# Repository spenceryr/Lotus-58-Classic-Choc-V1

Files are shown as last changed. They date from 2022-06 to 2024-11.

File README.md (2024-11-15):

### Notice! Project files in the development branches are NOT intended for public use in production of PCB's, may or may not be tested and may change or be removed without notice! 
If you order PCB's from these, YOU bear the sole responsibility for how these turn out!!! Please use the Gerber files for producing PCB's, found under the header 'Releases' instead (Look here >>). Also please note the difference between a 'Pre-release' (partially/fully untested, basically what I order a prototype PCB from to test) and a full actual 'Release' which is fully tested, built and ready to be used to produce PCB's.

# Lotus 58 Glow - Classic
#### Lotus 58 Classic is the wired designs of the Lotus keyboard. Wireless with BLE and 2.4Ghz dongled wireless reside in other repositories.

Starting with simple tweaks to the Lily58 Glow before ordering a set of PCB's it quickly spiraled out of control, and I ended up with what wasn't quite a Lily58 anymore, and although very similar in layout, it is no longer compatible with plate and case design. 

Because of this, it was renamed Lotus58, referencing another flower much like the lily in the name Lily58.

Lotus 58 Glow
(photo from reddit by u/bduzik)

## General Specifications

- Layout very similar to the original Lily58 family
- Per key RGB and RGB underglow
- Kaihl Hot-swap sockets for MX compatible switches
- Can be used as a standalone Gamepad for either hand
- Optional 0.91" OLED Screens and rotary encoders (one each per side)
- All components through-hole and easily soldered for beginners (SMD option for diodes)
- Designed with a sandwich-style plate/case as part of the design

## Layout variations

- Optional plate layout with OLED screen (Encoder can be placed on upper thumb key position)
- Optional plate layout with rotary encoder (Removes OLED screen for that side)  
- Optional plate layout with no hole for OLED or upper encoder (Encoder can be placed on upper thumb key position)

Layout variations Layout Variations

## 3D-printed Cases
**There are a couple of 'official' commissioned designs for 3D printed cases for the Lotus 58 Glow, available in a separate Git [here](https://github.com/TweetyDaBird/Lotus-Cases).** 

And you can find several more made by users using Google, and/or by joining the Discord channel and chatting to the builders/designers and users.

## Things to note when ordering PCB's
### Finding the Gerber files
If you are not aiming at modifying things, don't look for the gerber files in the folders, pretty please!</BR>
And please don't open yet another issue about it! </BR>
The gerber files are where they belong, zipped up in releases, look under that header for the version you want.

### Tips & Tricks
- Most PCB manufacturers have a MOQ of 5 PCB's, meaning you end up with 2½ keyboards when finished.
- The recommended PCB thickness is 1.6 mm, both for the main PCB and plates to allow the keyswitches to grip the plate and lock in place securely.

If ordering from [JLCPCB](https://www.jlcpcb.com) the plate Gerber files include a reference putting the added serial etc on a breakaway part for a clean look with minimal cost, if using another manufacturer it's possible they have additional fee's for removing the extra text, or you should consider plotting the Gerber files yourself with the correct reference for your manufacturer. Otherwise use the standard settings from JLPCB.

## Build guide
**Some basic build instructions are in the [WIKI](https://github.com/TweetyDaBird/Lotus-58-Classic/wiki), and I really try to keep these updated.** But please keep in mind that whenever these instructions conflict with information on the PCB silkscreen, the silkscreen is and always will be the correct source of information! It's always updated with the version, and the most current information for the PCB version in question. 

**The intent has always been that the keyboard should be able to be fully built with some very basic soldering skills and the instructions on the silkscreen.**

### Discord for further build help and discussions!

<a href="https://discord.gg/G6QzcJQUnm">Discuss on Discord</a>

## Buy a kit!
I sell complete kits, making it easy to build your keyboard, and it also supports prototypes for new wacky ones. 



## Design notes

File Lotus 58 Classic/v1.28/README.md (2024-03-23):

# Lotus 58 v1.28

Starting with simple tweaks to the Lily58 Glow before ordering a set of PCB's it quickly spiraled out of control, and I ended up with what wasn't quite a Lily58 anymore, and although very similar in layout, it is no longer compatible with plate and case design. 

Because of this, it was renamed Lotus58, referencing another flower much like the lily in the name Lily58.

# Lotus 58 Glow

Lotus 58 Glow
(photo from reddit by u/bduzik)

Fully backwards compatible physically identical outline for plates and identical firmware. Updates required to 3D cases for the reset/power switch.

# Parts needed

| Name of part | Qty. | Optional | Remarks | Aliexpress |
| --- | ---- | --- | --- | --- |
| PCB | 2 | X | 1,6 mm thick | X |
| Top plate | 2 | X | Optional layouts for OLED or encoder in top position. | X |
| Bottom plate | 2 | X | X | X |
| Kailh hotswap socket | 56-58 | X | Qty. depends on layout. | [link](https://www.aliexpress.com/item/-/4001051840976.html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) |
| Diodes 1N4841 (TH) or 1N4148W (SMD) | 56-58 | X | Qty. depends on layout. TH recommended for beginners. | [link(TH)](https://www.aliexpress.com/item/HOT-SELL-100-PCS-1N4148-DO-35-IN4148-Silicon-Switching-Diode-FREE-SHIPPMENT/32660088529.html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) or [link(SMD)](https://www.aliexpress.ru/item/-/1005002059571417.html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) |
| Capacitors 100 nF | 0-4 | ✔ | Qty. depends on layout. 2 needed for each encoder installed. | [link](https://www.aliexpress.com/item/-/32971478818.html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) |
| Resistor 4.7 kOhm | 0-4 | ✔ | Qty. depends on layout. 2 needed for each OLED installed. | [link](https://www.aliexpress.com/item/-/32847047012.html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) |
| 0.91" OLED Display | 0-2 | ✔ | Qty. depends on layout. | [link](https://www.aliexpress.com/item/-/4001028384269.html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) |
| TRRS jack PJ-320A | 2 | X | X | [link](https://www.aliexpress.com/item/-/4000114275750.html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) |
| M2 * 12 mm standoff | 10 | X | Rounded, max 3.7 mm in diameter | [link](https://www.aliexpress.com/item/-/32863484622.html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) |
| M2 * 4 mm screw | 20 | X | 4-8 mm length fits, low profile hex head recommended | [link](https://www.aliexpress.com/item/-/32966917947.html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) |
| TRRS cable | 1 | X | Needs to be 4 poles, more common 3 poles cable creates a shortcircuit | [link](https://www.aliexpress.com/item/32905903526.html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,searchweb201602_,searchweb201603_) |
| Silicon pads | 10 | X | X | [link](https://www.aliexpress.com/item/-/32912066603.html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) |
| Pro Micro | 2 | X | Can be built with various ProMicro clones as well as Elite C (Or nice!nano for a wireless keyboard) | [link](https://www.aliexpress.com/item/-/32849563958.html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) |
| MillMax low profile sockets | 1 | ✔ | Purchased as 1x64 pin and split | [link](https://eu.mouser.com/ProductDetail/575-641503)|
| Rotary Encoder | 0-2 | ✔ | Qty. depends on layout. | [link](https://www.aliexpress.com/item/10000056483250.html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,searchweb201602_,searchweb201603_) |
| Rotary Encoder Knob | 0-2 | ✔ | One needed for each encoder. Clearance for max 24 mm diameter, pick halfshaft or spline according to encoder choice.  | [link](https://www.aliexpress.com/item/10000056483250.html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,searchweb201602_,searchweb201603_) |
| SK6803/SK6805/SK6812 mini-E (3228) | 12/58 (70) | ✔ | Qty. depends on layout and if used as per-key or underglow (or both). Mini E are winged for easier soldering. | [link](https://www.aliexpress.com/item/4000475685852.html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,searchweb201602_,searchweb201603_) |
| SRV05-4	ESD | 0-2 | ✔ | Optional but recommended for ESD protection. | [link](https://www.lcsc.com/product-detail/Electrostatic-and-Surge-Protection-TVS-ESD_TECH-PUBLIC-SRV05-4_C558418.html)|
| MSK12C02 Slide switch | 0-2 | ✔ | Optional RGB select or Power switch | [link](https://www.lcsc.com/product-detail/Slide-Switches_SHOU-HAN-MSK12C02_C431540.html)|

## Things to note when ordering PCB's
### Finding the Gerber files
If you are not aiming at modifying things, don't look for the gerber files in the folders, pretty please!</BR>
And please don't open yet another issue about it! </BR>
The gerber files are where they belong, zipped up in releases, look under that header for the version you want.

### Tips & Tricks
- Most PCB manufacturers have a MOQ of 5 PCB's, meaning you end up with 2½ keyboards when finished.
- The recommended PCB thickness is 1.6 mm, both for the main PCB and plates to allow the keyswitches to grip the plate and lock in place securely.

If ordering from [JLPCB](https://www.jlpcb.com) the plate Gerber files include a reference putting the added serial etc on a breakaway part for a clean look with minimal cost, if using another manufacturer it's possible they have additional fee's for removing the extra text, or you should consider plotting the Gerber files yourself with the correct reference for your manufacturer. Otherwise use the standard settings from JLPCB.

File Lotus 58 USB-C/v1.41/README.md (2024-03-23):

# Lotus 58 v1.41

Starting with simple tweaks to the Lily58 Glow before ordering a set of PCB's it quickly spiraled out of control, and I ended up with what wasn't quite a Lily58 anymore, and although very similar in layout, it is no longer compatible with plate and case design. 

Because of this, it was renamed Lotus58, referencing another flower much like the lily in the name Lily58.

# Lotus 58 Glow

Lotus 58 Glow
(photo from reddit by u/bduzik)

Fully compatabile with v1.11, physically identical outline for plates etc. and identical Firmware.

# Parts needed

| Name of part | Qty. | Optional | Remarks | Aliexpress |
| --- | ---- | --- | --- | --- |
| PCB | 2 | X | 1,6mm thick | X |
| Top plate | 2 | X | Optional layouts for OLED or encoder in top position. | X |
| Bottom plate | 2 | X | X | X |
| Kailh hotswap socket | 56-58 | X | Qty. depends on layout. | [link](https://www.aliexpress.com/item/-/4001051840976.html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) |
| Diodes 1N4841 (TH) or 1N4148W (SMD) | 56-58 | X | Qty. depends on layout. TH recommended for beginners. | [link(TH)](https://www.aliexpress.com/item/HOT-SELL-100-PCS-1N4148-DO-35-IN4148-Silicon-Switching-Diode-FREE-SHIPPMENT/32660088529.html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) or [link(SMD)](https://www.aliexpress.ru/item/-/1005002059571417.html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) |
| Capacitors 100 nF | 0-4 | ✔ | Qty. depends on layout. 2 needed for each encoder installed. | [link](https://www.aliexpress.com/item/-/32971478818.html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) |
| 0.91" OLED Display | 0-2 | ✔ | Qty. depends on layout. | [link](https://www.aliexpress.com/item/-/4001028384269.html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) |
| USB C Connector | 2 | X | X | [link](https://www.lcsc.com/product-detail/USB-Connectors_G-Switch-GT-USB-7014C_C963373.html) |
| SRV05-4	ESD | 2 | X | ESD protection for USB link. | [link](https://www.lcsc.com/product-detail/Electrostatic-and-Surge-Protection-TVS-ESD_TECH-PUBLIC-SRV05-4_C558418.html)|
| Ferrite bead | 4 | X | ESD protection for USB link. | [link](https://www.lcsc.com/product-detail/Ferrite-Beads_Murata-Electronics-BLM18SG700TZ1D_C882974.html) |
| M2 * 10 mm standoff | 10 | X | Rounded, max 3.7 mm in diameter | [link](https://www.aliexpress.com/item/-/32863484622.html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) |
| M2 * 4 mm screw | 20 | X | 4-8 mm length fits, low profile hex head recommended | [link](https://www.aliexpress.com/item/-/32966917947.html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) |
| Silicon pads | 10 | X | X | [link](https://www.aliexpress.com/item/-/32912066603.html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) |
| Pro Micro | 2 | X | Can be built with various ProMicro clones as well as Elite C (Or nice!nano for a wireless keyboard) | [link](https://www.aliexpress.com/item/-/32849563958.html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) |
| MillMax low profile sockets | 1 | ✔ | Purchased as 1x64 pin and split | [link](https://eu.mouser.com/ProductDetail/575-641503)|
| Rotary Encoder | 0-2 | ✔ | Qty. depends on layout. | [link](https://www.aliexpress.com/item/10000056483250.html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,searchweb201602_,searchweb201603_) |
| Rotary Encoder Knob | 0-2 | ✔ | One needed for each encoder. Clearance for max 24 mm diameter, pick halfshaft or spline according to encoder choice.  | [link](https://www.aliexpress.com/item/10000056483250.html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,searchweb201602_,searchweb201603_) |
| SK6803/SK6805/SK6812 mini-E (3228) | 12/58 (70) | ✔ | Qty. depends on layout and if used as per-key or underglow (or both). Mini E are winged for easier soldering. (Note, these are often sold marked as 3535.)| [link](https://www.aliexpress.com/item/4000475685852.html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,searchweb201602_,searchweb201603_) |
| MSK12C02 Slide switch | 0-2 | ✔ | Optional RGB select or Power switch | [link](https://www.lcsc.com/product-detail/Slide-Switches_SHOU-HAN-MSK12C02_C431540.html)|

## Things to note when ordering PCB's
### Finding the Gerber files
If you are not aiming at modifying things, don't look for the gerber files in the folders, pretty please!</BR>
And please don't open yet another issue about it! </BR>
The gerber files are where they belong, zipped up in releases, look under that header for the version you want.

### Tips & Tricks
- Most PCB manufacturers have a MOQ of 5 PCB's, meaning you end up with 2½ keyboards when finished.
- The recommended PCB thickness is 1.6 mm, both for the main PCB and plates to allow the keyswitches to grip the plate and lock in place securely.

If ordering from [JLPCB](https://www.jlpcb.com) the plate Gerber files include a reference putting the added serial etc on a breakaway part for a clean look with minimal cost, if using another manufacturer it's possible they have additional fee's for removing the extra text, or you should consider plotting the Gerber files yourself with the correct reference for your manufacturer. Otherwise use the standard settings from JLPCB.

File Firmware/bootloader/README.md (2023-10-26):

# How do I flash nanoBoot to my Pro Micro controllers?

**Please note that this does NOT apply to RP2040 based controllers at all!**

## Flash the bootloader with an external programmer
Download the `nanoBoot-bootloader.hex` file and flash it using your choice of software/hardware.

#### Required fuse settings:
- lfuse memory = 0xFF or 0x7F (CKDIV8=1 or 0, 16CK+65ms)
- hfuse memory = 0xD6 (EESAVE=0, BOOTRST=0)
- efuse memory = 0xC7 (=0xF7, No BOD)

#### Example of fuse command
-U lfuse:w:0x7F:m -U hfuse:w:0xD6:m -U efuse:w:0xC7:m

## Using a pair of Pro Micro controllers as ISP programmers to flash the bootloader to both.
**This requires no external hardware, besides a few wires, and a little patience and time.** This way, you can easily and cheaply use the classic Atmega32u4 Pro Micro controllers a while longer, with either a full featured QMK keymap, or Vial if you accept some limitations in what features will fit.

1. Install Arduino IDE 1.8.19 and Pro Micro support:
  - Go to Files -> Preferences;
  - Paste `https://raw.githubusercontent.com/sparkfun/Arduino_Boards/master/IDE_Board_Manager/package_sparkfun_index.json` into "Additional Boards Manager URLs", press OK;
  - Go to Tools -> Board -> Boards Manager;
  - Search for `SparkFun AVR Boards`, install that, close the dialog window.
2. Burn the ArduinoISP sketch (through the normal USB connection):
  - Connect one of your two Pro Micros (we will call it `A` from now on);
  - In Arduino IDE, go to Tools -> Board -> SparkFun AVR Boards -> SparkFun Pro Micro;
  - As Processor choose the 5V 16MHz version;
  - As Port choose whatever the Arduino IDE gives you as an option (If you have more than 1 serial device connected, figure out which port is your Pro Micro by plugging and unplugging it)
  - In Arduino IDE, go to File -> Examples -> ArduinoISP -> ArduinoISP;
  - Hit Upload (either the arrow to the right next to the checkmark, or in Sketch -> Upload);
  - Close the Arduino IDE.
3. Connect the two Pro Micros:
  - Disconnect the Pro Micro `A` from the computer, get 6 jumper wires;
  - Connect the GND pin to GND pin, VCC to VCC, 15 to 15, 14 to 14, 16 to 16;
  - PAY ATTENTION: Connect the pin 10 of the Pro Micro `A`, to RST of the Pro Micro `B`;
  - Plug the Pro Micro `A` back into the computer.
4. Burn the supplied `nanoBoot-bootloader.hex` to the Pro Micro `B` (using `A´ as the ISP):
  - Now we will use `avrdude` included in the Arduino as a standalone executable (These instructions assume you use a terminal for your OS);
  - In the terminal go to the location where you downloaded the supplied `nanoBoot_ArduinoISP.hex` (use the `cd` command to jump between directories, `ls` (MacOS/Linux) or `dir` (Windows) displays content)
  - Run this command: `avrdude -c stk500v1 -p atmega32u4 -P /dev/ttyACM0 -b 19200 -U flash:w:nanoBoot-ArduinoISP.hex:i -U lfuse:w:0x7F:m -U hfuse:w:0xD6:m -U efuse:w:0xC7:m`  **WARNING: This command sets fuses on the board and wrong values of the fuses can brick the board beyond repair. This is done at your own responsibility!!** *Note: you might need to change the serial port given after -P from what is shown here, it should be the same you used when uploading the sketch through Arduino IDE.*
  - This flashes the same ArduinoISP sketch, but with the nanoBoot bootloader already included.
5. Burn the nanoBoot bootloader to the Pro Micro `A`:
  - Disconnect the Pro Micro `A` from the computer;
  - Swap the connections between the Pro Micros, since you will now swap the roles of the Pro Micros - Connect Pro Micro `A`'s RST to Pro Micro `B`'s pin 10;
  - Connect the Pro Micro `B` to the computer;
  - Run the same command as in step 4 (**the same warning applies**);
  - Congratulations! Now you have two Pro Micros with nanoBoot bootloaders!
6. Flash the Lotus58 firmware either from QMK Configurator, or using an already compiled binary
7. Test and celebrate!

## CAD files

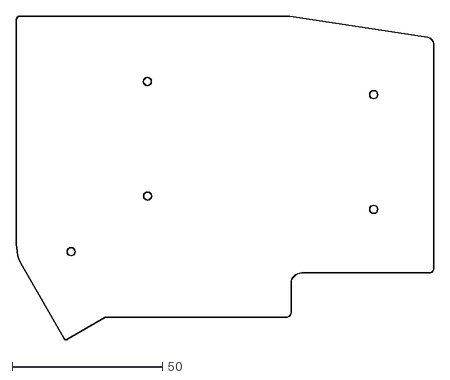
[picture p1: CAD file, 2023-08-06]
Plate/DXF/Laser_Cut_Bottom_Plate.dxf
139.1 x 107.7

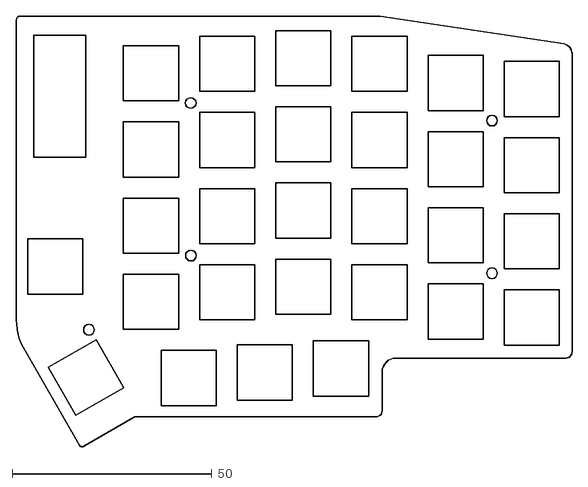
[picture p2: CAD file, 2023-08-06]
Plate/DXF/Laser_Cut_Top_Plate_OLED.dxf
139.1 x 107.7

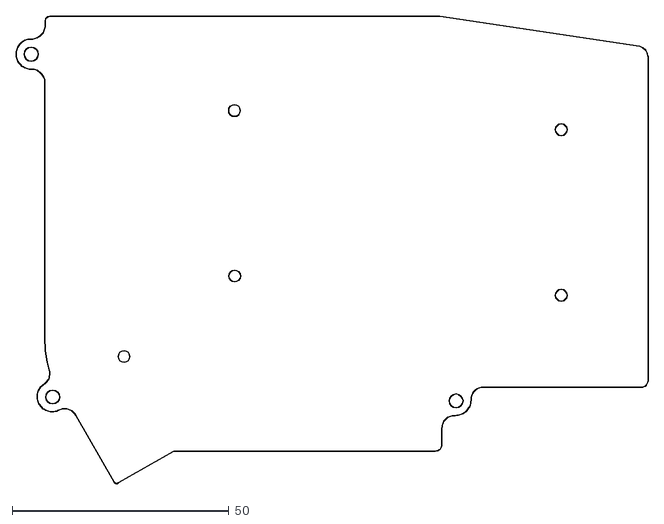
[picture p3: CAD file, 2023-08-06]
Plate/DXF/Laser_Cut_Bottom_Plate_TENT.dxf
145.7 x 107.7

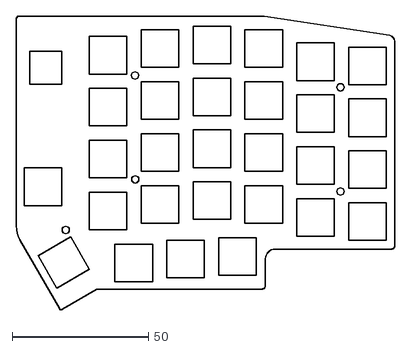
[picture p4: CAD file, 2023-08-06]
Plate/DXF/Laser_Cut_Top_Plate_ENC.dxf
139.1 x 107.7

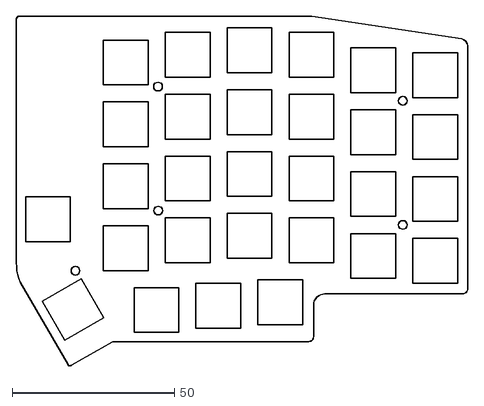
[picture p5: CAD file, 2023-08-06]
Plate/DXF/Laser_Cut_Top_Plate_Blank.dxf
139.1 x 107.7

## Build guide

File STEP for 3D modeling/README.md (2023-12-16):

### STEP files used for 3D modeling cases etc.
All relevant components are modeled and present on both sides of the PCB, as they are not always 100% symmetrical (placement depends on traces etc). Keep in mind that the modeling should as standard use the component placed on the bottom side of the PCB for each respective hand.

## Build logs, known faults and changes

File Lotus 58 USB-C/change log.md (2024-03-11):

Change Log Lotus 58 Glow USB-C

- v1.30 - Initial release
   - This version adds an USB-C link between hands instead of the TRRS link. This allows hot-plugging the link without damage.
   - NO support for wirless builds (battery/power switch) as the USB-C link isn't suitable for this.
- v1.33 - Intermediary release
  - Minor tweaks to the ESD protection circuit
  - The RGB circuit now allows ALL RGB to be soldered in place, and switches the powerline instead of the data line as previously.
  - ALL RGB uses SK6812 mini-e
  - Reset switch and slide switch is moved for better 3D printed cases. 
- v1.40 - Second major release
  - Moved serial data to D+/- for better cable compatibility.
  - Added solder jumpers for RGB selection without switch
- v1.41 - Intermediary release
  - Corrected minor silkscreen inconsistencies.

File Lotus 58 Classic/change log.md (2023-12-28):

Change Log Lotus 58 Glow TRRS/Classic

- v1.00 - Initial release
   - This verison unfortunately had various RGB issues. Used through hole mounted SK6812 mini RGB's for both per-key and glow.
- v1.11 - Intermediary release
  - RGB issues fixed, improved silkscreen for easier building.
- v1.23 - Second release
  - Greatly improved design, per-key moved to SK6812 mini-e winged RGB, and glow remains as surface mounted SK6812 mini.
  - Added support for battery connector and power switch for wireless builds.
- v1.24 - Intermediary release
   - Added Silkscreen build instructions
  - Added TRRS ESD protection
  - Removed i2c resistors
  - Repositioned reset for easier access
  - Minor cleanup of routing and silkscreen
- v1.26 - Third Release
  - Brings TRRS variant to feature parity with USB C variant by moving ALL RGB to SK6812 mini-e.
  - All RGB can be soldered, and either glow or key can be selected to be active (drawing power)
  - Switch positions are the same as USB-C so reset and power switch can now be on both sides of PCB (easier 3D printing)
  - Better footprints, so easier to solder.
  - Since the TRRS version already have a power switch, the RGB is an internal switch, placed where you need to disassemble, alternatively hard soldered jumpers.
- v1.27 - Intermediary release
  - Improved Silkscreen/build instructions on PCB
- v1.28 - Fourth release
  - Possible to select the function of the external slide switch, setting it as a power switch for wireless builds, or to select RGB for a wired build

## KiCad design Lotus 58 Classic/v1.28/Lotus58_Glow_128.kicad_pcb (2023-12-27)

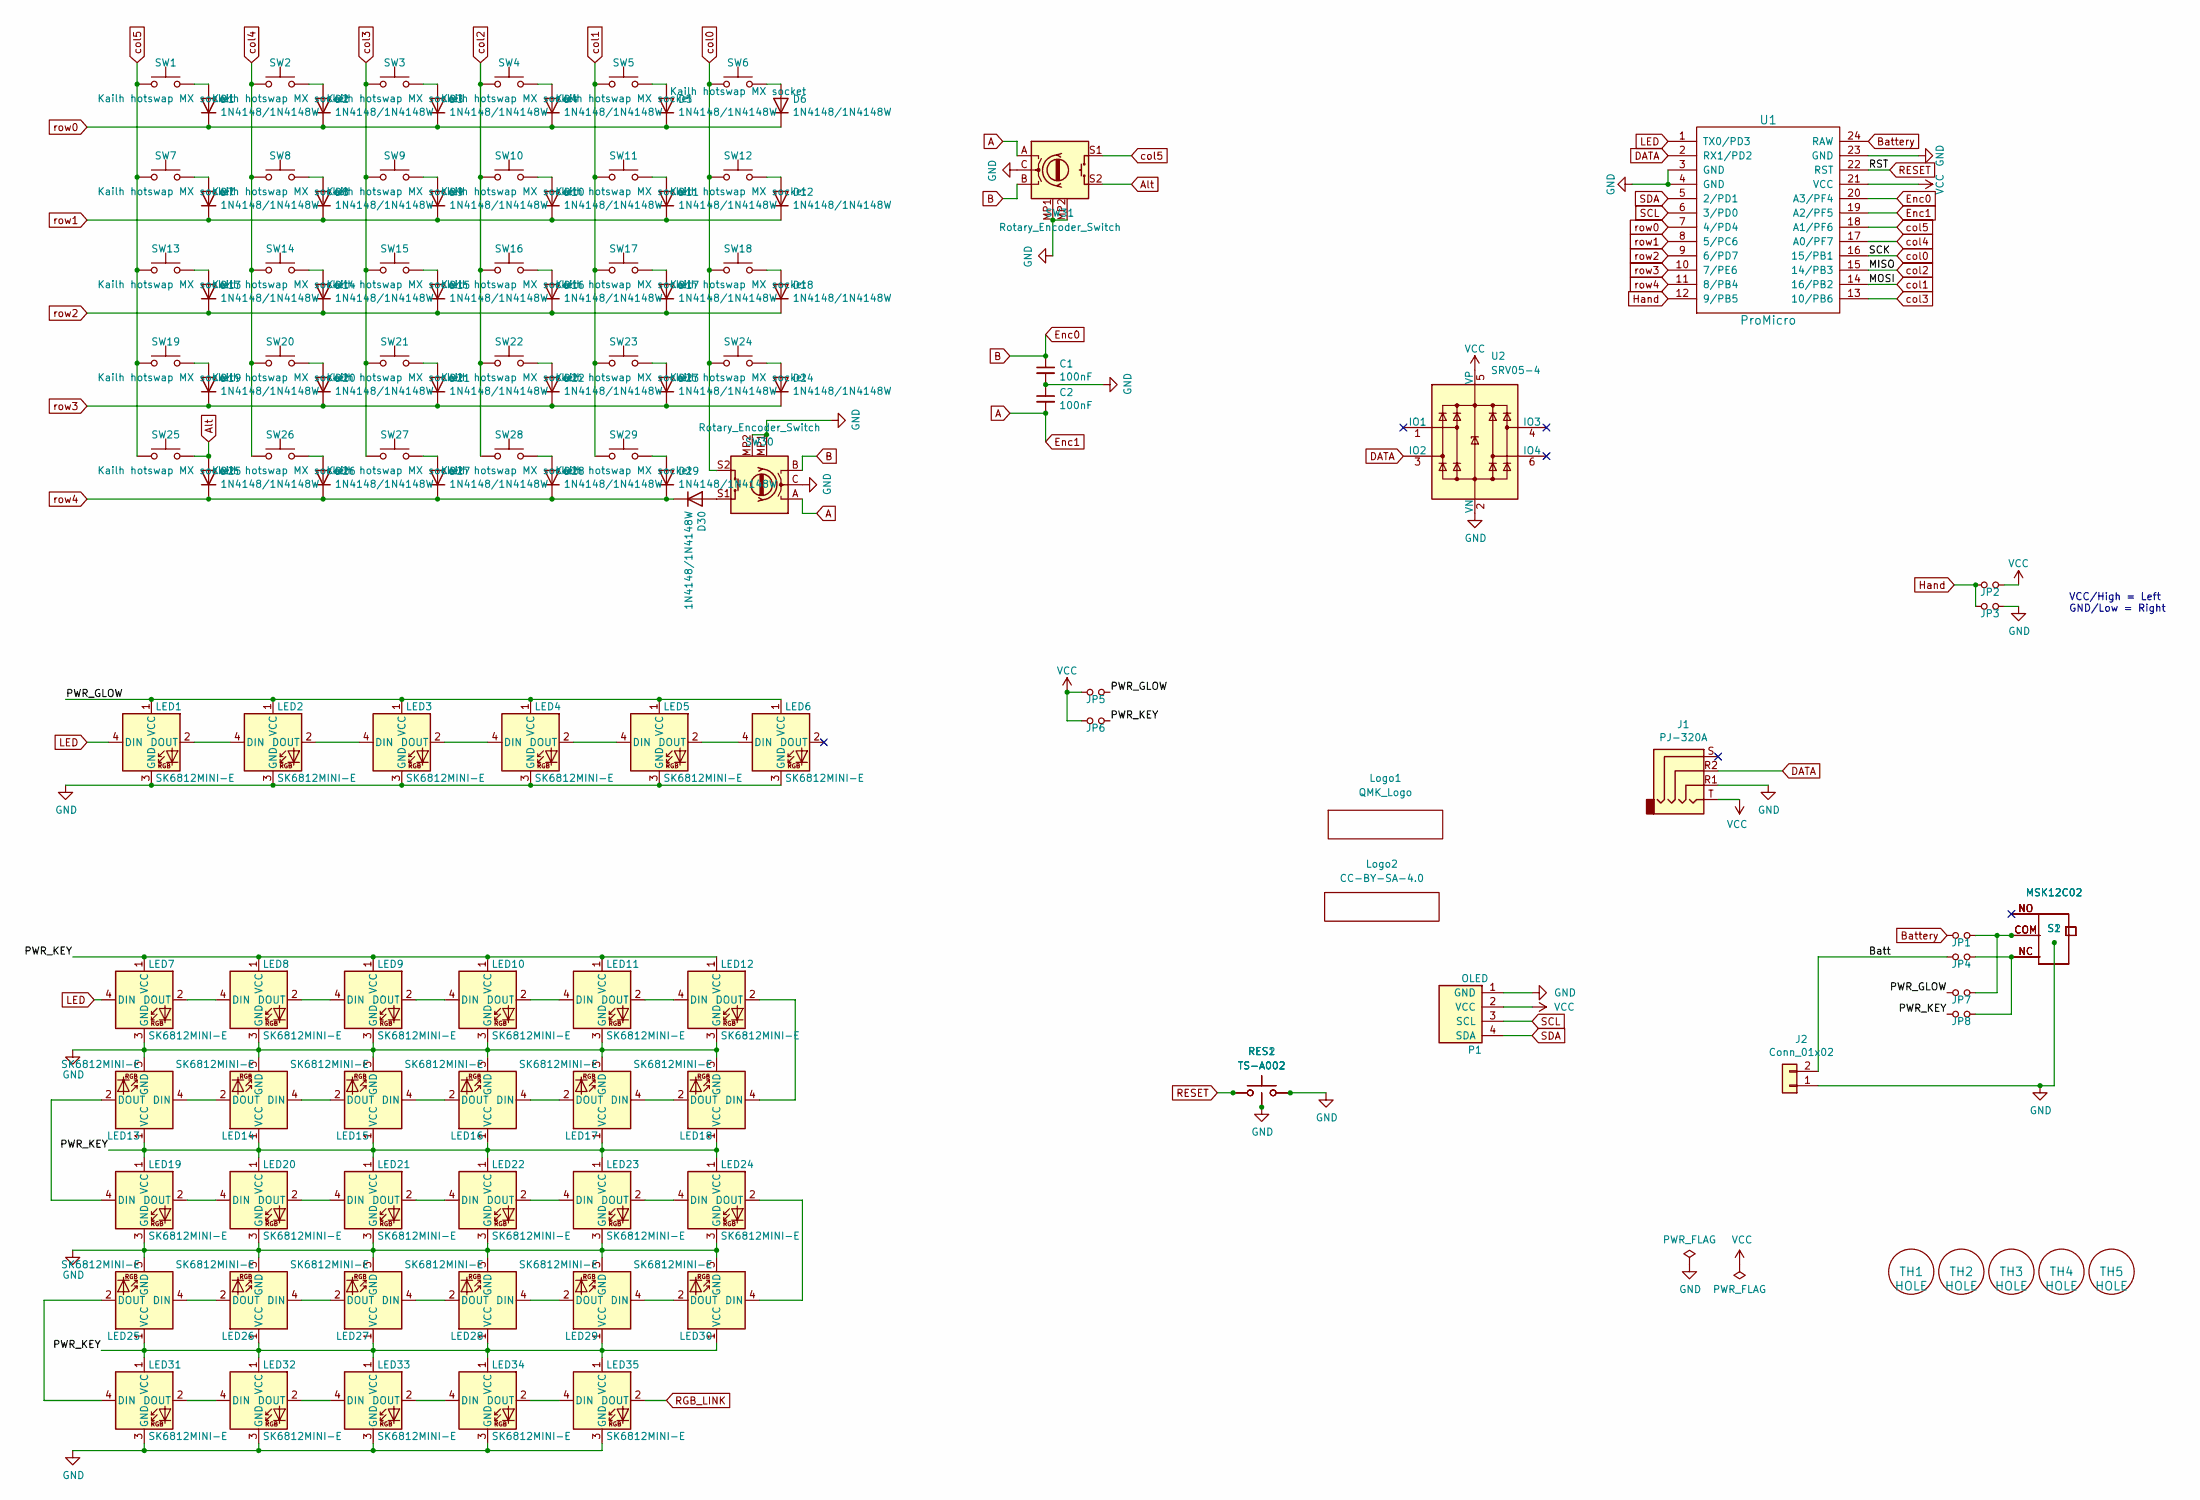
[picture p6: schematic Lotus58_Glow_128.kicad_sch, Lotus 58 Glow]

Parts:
C1, C2: 100nF; RESISTOR_Reversible
D1, D2, D3, D4, D5, D6, D7, D8, D9, D10, D11, D12, D13, D14, D15, D16, D17, D18, D19, D20, D21, D22, D23, D24, D25, D26, D27, D28, D29, D30: 1N4148/1N4148W; Diode_DO35_SOD123
J1: PJ-320A; MJ-4PP-9_alim
J2: Conn_01x02; PinHeader_1x02_P2.54mm_Vertical
JP1, JP4, JP5, JP6, JP7, JP8: FULL; Jumper_min_v2
JP2: LEFT; Jumper_min_v2
JP3: RIGHT; Jumper_min_v2
LED1, LED2, LED3, LED4, LED5, LED6, LED7, LED8, LED9, LED10, LED11, LED12, LED13, LED14, LED15, LED16, LED17, LED18, LED19, LED20, LED21, LED22, LED23, LED24, LED25, LED26, LED27, LED28, LED29, LED30, LED31, LED32, LED33, LED34, LED35: SK6812MINI-E; MX_SK6812MINI-E_REVERSIBLE
Logo1: QMK_Logo; qmk logo
Logo2: CC-BY-SA-4.0; CC_BY_SA_40_line
P1: OLED; SSD1306-0.91-OLED-4pin-128x32 doublesided
RES1, RES2: TS-A002; YTS-A002; LCSC C2888934
S1, S2: MSK12C02; Manufacturer_Part_Number MSK12C02
SW1, SW2, SW3, SW4, SW5, SW6, SW7, SW8, SW9, SW10, SW11, SW12, SW13, SW14, SW15, SW16, SW17, SW18, SW19, SW20, SW21, SW22, SW23, SW24, SW25, SW26, SW27, SW28, SW29: Kailh hotswap MX socket; Kailh_socket_MX_reversible_RGB
SW30: Rotary_Encoder_Switch; RotaryEncoder_Alps_EC11E-Switch_Vertical_H20_special
SW31: Rotary_Encoder_Switch; RotaryEncoder_Alps_EC11E-Switch_Special
TH1, TH2, TH3, TH4, TH5: HOLE; Spacer PCB hole
U1: ProMicro; ProMicro_Reversible_orig
U2: SRV05-4; SOT-23-6

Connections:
/Batt: J2.2, JP4.1
/PWR_GLOW: JP5.2, JP7.1, LED1.1 (VCC), LED2.1 (VCC), LED3.1 (VCC), LED4.1 (VCC), LED5.1 (VCC), LED6.1 (VCC)
/PWR_KEY: JP6.2, JP8.1, LED7.1 (VCC), LED8.1 (VCC), LED9.1 (VCC), LED10.1 (VCC), LED11.1 (VCC), LED12.1 (VCC), LED13.1 (VCC), LED14.1 (VCC), LED15.1 (VCC), LED16.1 (VCC), LED17.1 (VCC), LED18.1 (VCC), LED19.1 (VCC), LED20.1 (VCC), LED21.1 (VCC), LED22.1 (VCC), LED23.1 (VCC), LED24.1 (VCC), LED25.1 (VCC), LED26.1 (VCC), LED27.1 (VCC), LED28.1 (VCC), LED29.1 (VCC), LED30.1 (VCC), LED31.1 (VCC), LED32.1 (VCC), LED33.1 (VCC), LED34.1 (VCC), LED35.1 (VCC)
A: C2.2, SW30.A, SW31.A, U1.19 (A2/PF5)
Alt: D25.2 (A), SW25.2, SW31.S2
B: C1.1, SW30.B, SW31.B, U1.20 (A3/PF4)
Battery: JP1.1, U1.24 (RAW)
DATA: J1.R2, U1.2 (RX1/PD2), U2.3 (IO2)
GND: C1.2, C2.1, J1.R1, J2.1, JP3.1, LED1.3 (GND), LED2.3 (GND), LED3.3 (GND), LED4.3 (GND), LED5.3 (GND), LED6.3 (GND), LED7.3 (GND), LED8.3 (GND), LED9.3 (GND), LED10.3 (GND), LED11.3 (GND), LED12.3 (GND), LED13.3 (GND), LED14.3 (GND), LED15.3 (GND), LED16.3 (GND), LED17.3 (GND), LED18.3 (GND), LED19.3 (GND), LED20.3 (GND), LED21.3 (GND), LED22.3 (GND), LED23.3 (GND), LED24.3 (GND), LED25.3 (GND), LED26.3 (GND), LED27.3 (GND), LED28.3 (GND), LED29.3 (GND), LED30.3 (GND), LED31.3 (GND), LED32.3 (GND), LED33.3 (GND), LED34.3 (GND), LED35.3 (GND), P1.1 (GND), RES1.2, RES1.3, RES2.2, RES2.3, S1.MP (GND), S2.MP (GND), SW30.C, SW30.MP1 (GND), SW30.MP2 (GND), SW31.C, SW31.MP1 (GND), SW31.MP2 (GND), U1.3 (GND), U1.4 (GND), U1.23 (GND), U2.2 (VN)
Hand: JP2.2, JP3.2, U1.12 (9/PB5)
LED: LED1.4 (DIN), LED7.4 (DIN), U1.1 (TX0/PD3)
unnamed: D2.2 (A), SW2.2
unnamed: D3.2 (A), SW3.2
unnamed: D4.2 (A), SW4.2
unnamed: D5.2 (A), SW5.2
unnamed: D6.2 (A), SW6.2
unnamed: D7.2 (A), SW7.2
unnamed: D8.2 (A), SW8.2
unnamed: D9.2 (A), SW9.2
unnamed: D10.2 (A), SW10.2
unnamed: D11.2 (A), SW11.2
unnamed: D12.2 (A), SW12.2
unnamed: D13.2 (A), SW13.2
unnamed: D14.2 (A), SW14.2
unnamed: D15.2 (A), SW15.2
unnamed: D16.2 (A), SW16.2
unnamed: D17.2 (A), SW17.2
unnamed: D18.2 (A), SW18.2
unnamed: D19.2 (A), SW19.2
unnamed: D20.2 (A), SW20.2
unnamed: D21.2 (A), SW21.2
unnamed: D22.2 (A), SW22.2
unnamed: D23.2 (A), SW23.2
unnamed: D24.2 (A), SW24.2
unnamed: D26.2 (A), SW26.2
unnamed: D27.2 (A), SW27.2
unnamed: D28.2 (A), SW28.2
unnamed: D29.2 (A), SW29.2
unnamed: D30.2 (A), SW30.S1
unnamed: JP1.2, JP7.2, S1.COM, S2.COM
unnamed: JP4.2, JP8.2, S1.NC, S2.NC
unnamed: LED1.2 (DOUT), LED2.4 (DIN)
unnamed: LED2.2 (DOUT), LED3.4 (DIN)
unnamed: LED3.2 (DOUT), LED4.4 (DIN)
unnamed: LED4.2 (DOUT), LED5.4 (DIN)
unnamed: LED5.2 (DOUT), LED6.4 (DIN)
unnamed: LED7.2 (DOUT), LED8.4 (DIN)
unnamed: LED8.2 (DOUT), LED9.4 (DIN)
unnamed: LED9.2 (DOUT), LED10.4 (DIN)
unnamed: LED10.2 (DOUT), LED11.4 (DIN)
unnamed: LED11.2 (DOUT), LED12.4 (DIN)
unnamed: LED12.2 (DOUT), LED18.4 (DIN)
unnamed: LED13.4 (DIN), LED14.2 (DOUT)
unnamed: LED13.2 (DOUT), LED19.4 (DIN)
unnamed: LED14.4 (DIN), LED15.2 (DOUT)
unnamed: LED15.4 (DIN), LED16.2 (DOUT)
unnamed: LED16.4 (DIN), LED17.2 (DOUT)
unnamed: LED17.4 (DIN), LED18.2 (DOUT)
unnamed: LED19.2 (DOUT), LED20.4 (DIN)
unnamed: LED20.2 (DOUT), LED21.4 (DIN)
unnamed: LED21.2 (DOUT), LED22.4 (DIN)
unnamed: LED22.2 (DOUT), LED23.4 (DIN)
unnamed: LED23.2 (DOUT), LED24.4 (DIN)
unnamed: LED24.2 (DOUT), LED30.4 (DIN)
unnamed: LED25.4 (DIN), LED26.2 (DOUT)
unnamed: LED25.2 (DOUT), LED31.4 (DIN)
unnamed: LED26.4 (DIN), LED27.2 (DOUT)
unnamed: LED27.4 (DIN), LED28.2 (DOUT)
unnamed: LED28.4 (DIN), LED29.2 (DOUT)
unnamed: LED29.4 (DIN), LED30.2 (DOUT)
unnamed: LED31.2 (DOUT), LED32.4 (DIN)
unnamed: LED32.2 (DOUT), LED33.4 (DIN)
unnamed: LED33.2 (DOUT), LED34.4 (DIN)
unnamed: LED34.2 (DOUT), LED35.4 (DIN)
RESET: RES1.1, RES2.1, U1.22 (RST)
RGB_LINK: LED35.2 (DOUT)
SCL: P1.3 (SCL), U1.6 (3/PD0)
SDA: P1.4 (SDA), U1.5 (2/PD1)
VCC: J1.T, JP2.1, JP5.1, JP6.1, P1.2 (VCC), U1.21 (VCC), U2.5 (VP)
col0: SW6.1, SW12.1, SW18.1, SW24.1, SW30.S2, U1.16 (15/PB1)
col1: SW5.1, SW11.1, SW17.1, SW23.1, SW29.1, U1.14 (16/PB2)
col2: SW4.1, SW10.1, SW16.1, SW22.1, SW28.1, U1.15 (14/PB3)
col3: SW3.1, SW9.1, SW15.1, SW21.1, SW27.1, U1.13 (10/PB6)
col4: SW2.1, SW8.1, SW14.1, SW20.1, SW26.1, U1.17 (A0/PF7)
row0: D1.1 (K), D2.1 (K), D3.1 (K), D4.1 (K), D5.1 (K), D6.1 (K), U1.7 (4/PD4)
row1: D7.1 (K), D8.1 (K), D9.1 (K), D10.1 (K), D11.1 (K), D12.1 (K), U1.8 (5/PC6)
row2: D13.1 (K), D14.1 (K), D15.1 (K), D16.1 (K), D17.1 (K), D18.1 (K), U1.9 (6/PD7)
row3: D19.1 (K), D20.1 (K), D21.1 (K), D22.1 (K), D23.1 (K), D24.1 (K), U1.10 (7/PE6)
row4: D25.1 (K), D26.1 (K), D27.1 (K), D28.1 (K), D29.1 (K), D30.1 (K), U1.11 (8/PB4)

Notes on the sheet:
VCC/High = Left GND/Low = Right

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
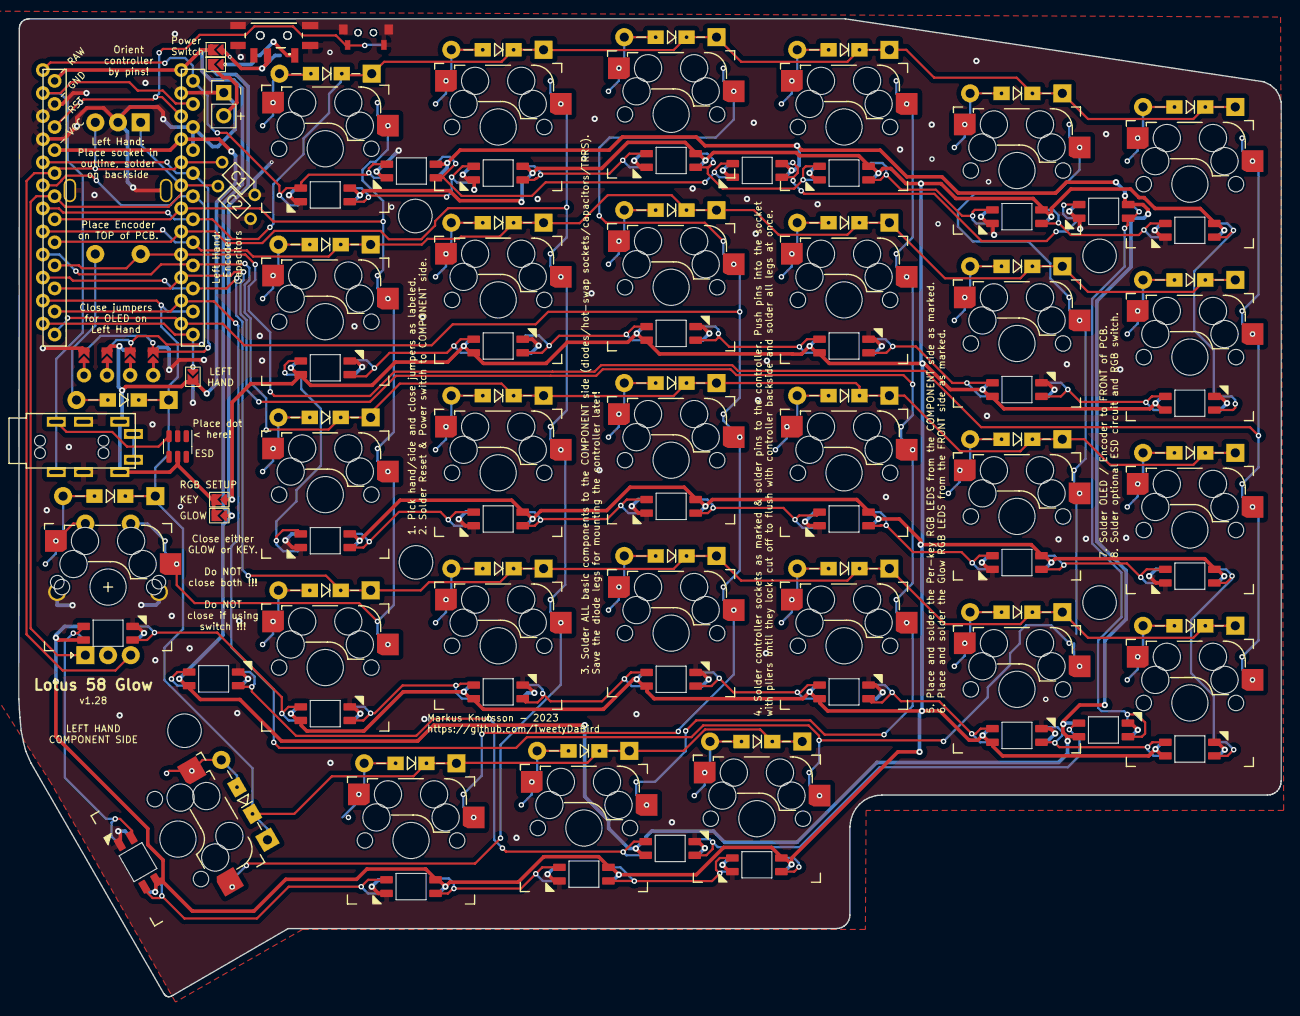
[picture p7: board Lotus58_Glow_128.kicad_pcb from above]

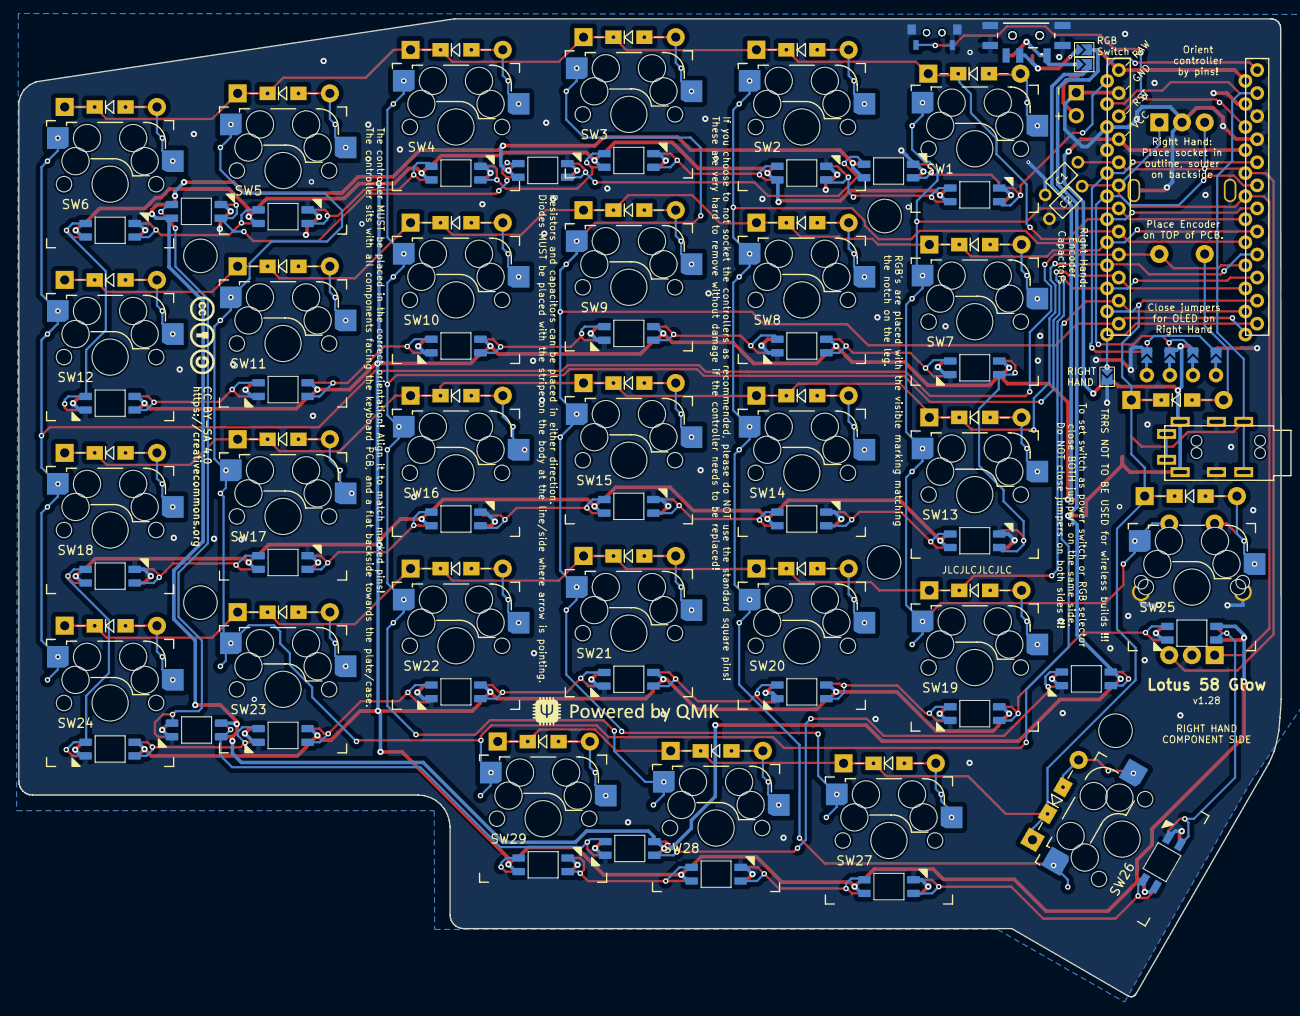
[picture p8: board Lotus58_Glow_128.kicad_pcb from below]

Board: 2 copper layers, 139.1 x 107.7 mm, 122 parts (73 on the bottom side), 90 nets.

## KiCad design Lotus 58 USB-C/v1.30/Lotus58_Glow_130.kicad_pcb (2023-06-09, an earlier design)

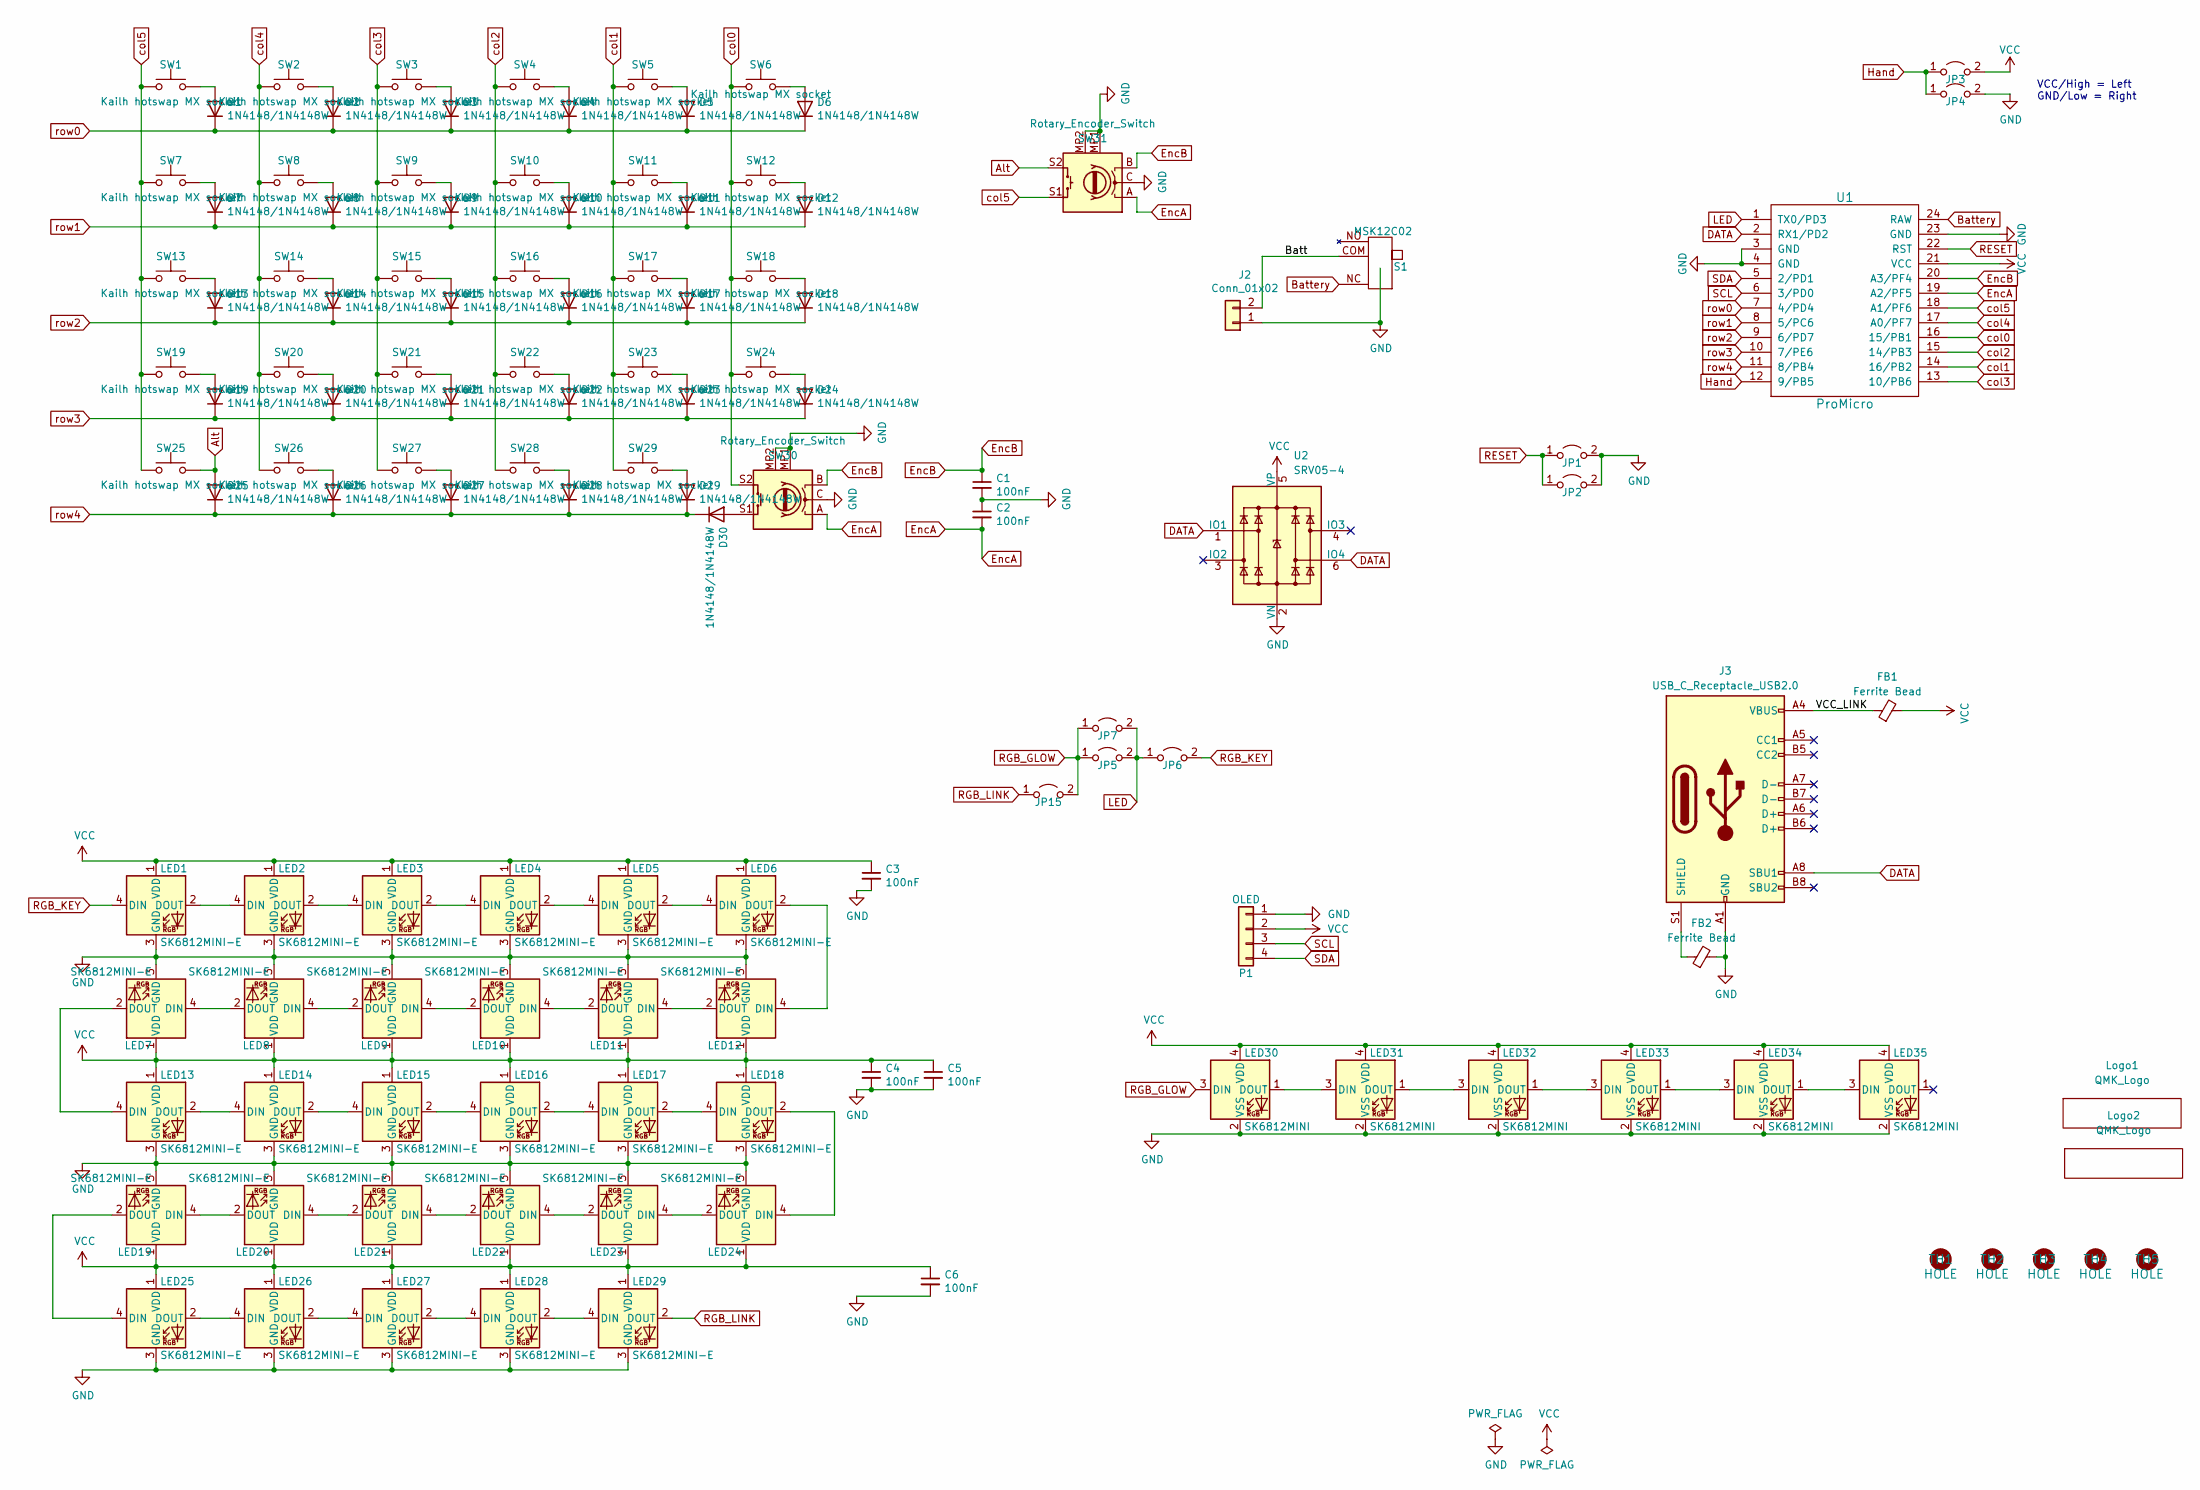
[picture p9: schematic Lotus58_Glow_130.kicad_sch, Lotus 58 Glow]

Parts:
C1, C2, C3, C4, C5, C6: 100nF; RESISTOR_Reversible
D1, D2, D3, D4, D5, D6, D7, D8, D9, D10, D11, D12, D13, D14, D15, D16, D17, D18, D19, D20, D21, D22, D23, D24, D25, D26, D27, D28, D29, D30: 1N4148/1N4148W; Diode_DO35_SOD123
FB1, FB2: Ferrite Bead; C_0603_1608Metric_Pad1.08x0.95mm_HandSolder; LCSC C882974
J2: Conn_01x02; PinHeader_1x02_P2.54mm_Vertical
J3: USB_C_Receptacle_USB2.0; Molex-216990_GCT-USB45xx_HRO-TYPE-C-31-M-13x-PiMicro
JP1, JP2: RESET; Jumper_Mini
JP3: LEFT; Jumper_Mini
JP4: RIGHT; Jumper_Mini
JP5, JP6, JP7, JP15: FULL; Jumper_Mini
LED1, LED2, LED3, LED4, LED5, LED6, LED7, LED8, LED9, LED10, LED11, LED12, LED13, LED14, LED15, LED16, LED17, LED18, LED19, LED20, LED21, LED22, LED23, LED24, LED25, LED26, LED27, LED28, LED29: SK6812MINI-E; MX_SK6812MINI-E_REVERSIBLE
LED30, LED31, LED32, LED33, LED34, LED35: SK6812MINI; LED_SK6812MINI_PLCC4_3.5x3.5mm_P1.75mmdouble
Logo1, Logo2: QMK_Logo; qmk logo
P1: OLED; SSD1306-0.91-OLED-4pin-128x32 doublesided
S1: MSK12C02; Manufacturer_Part_Number MSK12C02
SW1, SW2, SW3, SW4, SW5, SW6, SW7, SW8, SW9, SW10, SW11, SW12, SW13, SW14, SW15, SW16, SW17, SW18, SW19, SW20, SW21, SW22, SW23, SW24, SW25, SW26, SW27, SW28, SW29: Kailh hotswap MX socket; SW_MX_HotSwap_Reversible
SW30: Rotary_Encoder_Switch; Encoder_Alps_EC11E_Small
SW31: Rotary_Encoder_Switch; Encoder_Alps_EC11E_Offset_pad
TH1, TH2, TH3, TH4, TH5: HOLE; Spacer PCB hole
U1: ProMicro; ProMicro_jumpers
U2: SRV05-4; SOT-23-6; LCSC C558418

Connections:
/Batt: J2.2, S1.COM
/VCC_LINK: FB1.1, J3.A4 (VBUS), J3.A9 (VBUS), J3.B4 (VBUS), J3.B9 (VBUS)
Alt: D25.2 (A), SW25.1, SW31.S2
Battery: S1.NC, U1.24 (RAW)
DATA: J3.A8 (SBU1), U1.2 (RX1/PD2), U2.1 (IO1), U2.6 (IO4)
EncA: C2.2, SW30.A, SW31.A, U1.19 (A2/PF5)
EncB: C1.1, SW30.B, SW31.B, U1.20 (A3/PF4)
GND: C1.2, C2.1, C3.2, C4.2, C5.2, C6.2, FB2.2, J2.1, J3.A1 (GND), J3.A12 (GND), J3.B1 (GND), J3.B12 (GND), JP1.2 (B), JP2.2 (B), JP4.2 (B), LED1.3 (GND), LED2.3 (GND), LED3.3 (GND), LED4.3 (GND), LED5.3 (GND), LED6.3 (GND), LED7.3 (GND), LED8.3 (GND), LED9.3 (GND), LED10.3 (GND), LED11.3 (GND), LED12.3 (GND), LED13.3 (GND), LED14.3 (GND), LED15.3 (GND), LED16.3 (GND), LED17.3 (GND), LED18.3 (GND), LED19.3 (GND), LED20.3 (GND), LED21.3 (GND), LED22.3 (GND), LED23.3 (GND), LED24.3 (GND), LED25.3 (GND), LED26.3 (GND), LED27.3 (GND), LED28.3 (GND), LED29.3 (GND), LED30.2 (VSS), LED31.2 (VSS), LED32.2 (VSS), LED33.2 (VSS), LED34.2 (VSS), LED35.2 (VSS), P1.1, S1.MP (GND), SW30.C, SW30.MP1 (GND), SW30.MP2 (GND), SW31.C, SW31.MP1 (GND), SW31.MP2 (GND), U1.3 (GND), U1.4 (GND), U1.23 (GND), U2.2 (VN)
Hand: JP3.1 (A), JP4.1 (A), U1.12 (9/PB5)
LED: JP5.2 (B), JP6.1 (A), JP7.2 (B), U1.1 (TX0/PD3)
unnamed: D1.2 (A), SW1.1
unnamed: D2.2 (A), SW2.1
unnamed: D3.2 (A), SW3.1
unnamed: D4.2 (A), SW4.1
unnamed: D5.2 (A), SW5.1
unnamed: D6.2 (A), SW6.1
unnamed: D7.2 (A), SW7.1
unnamed: D8.2 (A), SW8.1
unnamed: D9.2 (A), SW9.1
unnamed: D10.2 (A), SW10.1
unnamed: D11.2 (A), SW11.1
unnamed: D12.2 (A), SW12.1
unnamed: D13.2 (A), SW13.1
unnamed: D14.2 (A), SW14.1
unnamed: D15.2 (A), SW15.1
unnamed: D16.2 (A), SW16.1
unnamed: D17.2 (A), SW17.1
unnamed: D18.2 (A), SW18.1
unnamed: D19.2 (A), SW19.1
unnamed: D20.2 (A), SW20.1
unnamed: D21.2 (A), SW21.1
unnamed: D22.2 (A), SW22.1
unnamed: D23.2 (A), SW23.1
unnamed: D24.2 (A), SW24.1
unnamed: D26.2 (A), SW26.1
unnamed: D27.2 (A), SW27.1
unnamed: D28.2 (A), SW28.1
unnamed: D29.2 (A), SW29.1
unnamed: D30.2 (A), SW30.S1
unnamed: FB2.1, J3.S1 (SHIELD)
unnamed: LED1.2 (DOUT), LED2.4 (DIN)
unnamed: LED2.2 (DOUT), LED3.4 (DIN)
unnamed: LED3.2 (DOUT), LED4.4 (DIN)
unnamed: LED4.2 (DOUT), LED5.4 (DIN)
unnamed: LED5.2 (DOUT), LED6.4 (DIN)
unnamed: LED7.4 (DIN), LED8.2 (DOUT)
unnamed: LED8.4 (DIN), LED9.2 (DOUT)
unnamed: LED10.4 (DIN), LED11.2 (DOUT)
unnamed: LED9.4 (DIN), LED10.2 (DOUT)
unnamed: LED11.4 (DIN), LED12.2 (DOUT)
unnamed: LED6.2 (DOUT), LED12.4 (DIN)
unnamed: LED7.2 (DOUT), LED13.4 (DIN)
unnamed: LED13.2 (DOUT), LED14.4 (DIN)
unnamed: LED14.2 (DOUT), LED15.4 (DIN)
unnamed: LED15.2 (DOUT), LED16.4 (DIN)
unnamed: LED16.2 (DOUT), LED17.4 (DIN)
unnamed: LED17.2 (DOUT), LED18.4 (DIN)
unnamed: LED18.2 (DOUT), LED24.4 (DIN)
unnamed: LED19.4 (DIN), LED20.2 (DOUT)
unnamed: LED19.2 (DOUT), LED25.4 (DIN)
unnamed: LED20.4 (DIN), LED21.2 (DOUT)
unnamed: LED21.4 (DIN), LED22.2 (DOUT)
unnamed: LED22.4 (DIN), LED23.2 (DOUT)
unnamed: LED23.4 (DIN), LED24.2 (DOUT)
unnamed: LED25.2 (DOUT), LED26.4 (DIN)
unnamed: LED26.2 (DOUT), LED27.4 (DIN)
unnamed: LED27.2 (DOUT), LED28.4 (DIN)
unnamed: LED28.2 (DOUT), LED29.4 (DIN)
unnamed: LED30.1 (DOUT), LED31.3 (DIN)
unnamed: LED31.1 (DOUT), LED32.3 (DIN)
unnamed: LED32.1 (DOUT), LED33.3 (DIN)
unnamed: LED33.1 (DOUT), LED34.3 (DIN)
unnamed: LED34.1 (DOUT), LED35.3 (DIN)
RESET: JP1.1 (A), JP2.1 (A), U1.22 (RST)
RGB_GLOW: JP5.1 (A), JP7.1 (A), JP15.2 (B), LED30.3 (DIN)
RGB_KEY: JP6.2 (B), LED1.4 (DIN)
RGB_LINK: JP15.1 (A), LED29.2 (DOUT)
SCL: P1.3, U1.6 (3/PD0)
SDA: P1.4, U1.5 (2/PD1)
VCC: C3.1, C4.1, C5.1, C6.1, FB1.2, JP3.2 (B), LED1.1 (VDD), LED2.1 (VDD), LED3.1 (VDD), LED4.1 (VDD), LED5.1 (VDD), LED6.1 (VDD), LED7.1 (VDD), LED8.1 (VDD), LED9.1 (VDD), LED10.1 (VDD), LED11.1 (VDD), LED12.1 (VDD), LED13.1 (VDD), LED14.1 (VDD), LED15.1 (VDD), LED16.1 (VDD), LED17.1 (VDD), LED18.1 (VDD), LED19.1 (VDD), LED20.1 (VDD), LED21.1 (VDD), LED22.1 (VDD), LED23.1 (VDD), LED24.1 (VDD), LED25.1 (VDD), LED26.1 (VDD), LED27.1 (VDD), LED28.1 (VDD), LED29.1 (VDD), LED30.4 (VDD), LED31.4 (VDD), LED32.4 (VDD), LED33.4 (VDD), LED34.4 (VDD), LED35.4 (VDD), P1.2, U1.21 (VCC), U2.5 (VP)
col0: SW6.2, SW12.2, SW18.2, SW24.2, SW30.S2, U1.16 (15/PB1)
col1: SW5.2, SW11.2, SW17.2, SW23.2, SW29.2, U1.14 (16/PB2)
col2: SW4.2, SW10.2, SW16.2, SW22.2, SW28.2, U1.15 (14/PB3)
col3: SW3.2, SW9.2, SW15.2, SW21.2, SW27.2, U1.13 (10/PB6)
col4: SW2.2, SW8.2, SW14.2, SW20.2, SW26.2, U1.17 (A0/PF7)
col5: SW1.2, SW7.2, SW13.2, SW19.2, SW25.2, SW31.S1, U1.18 (A1/PF6)
row0: D1.1 (K), D2.1 (K), D3.1 (K), D4.1 (K), D5.1 (K), D6.1 (K), U1.7 (4/PD4)
row1: D7.1 (K), D8.1 (K), D9.1 (K), D10.1 (K), D11.1 (K), D12.1 (K), U1.8 (5/PC6)
row2: D13.1 (K), D14.1 (K), D15.1 (K), D16.1 (K), D17.1 (K), D18.1 (K), U1.9 (6/PD7)
row3: D19.1 (K), D20.1 (K), D21.1 (K), D22.1 (K), D23.1 (K), D24.1 (K), U1.10 (7/PE6)
row4: D25.1 (K), D26.1 (K), D27.1 (K), D28.1 (K), D29.1 (K), D30.1 (K), U1.11 (8/PB4)

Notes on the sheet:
VCC/High = Left GND/Low = Right

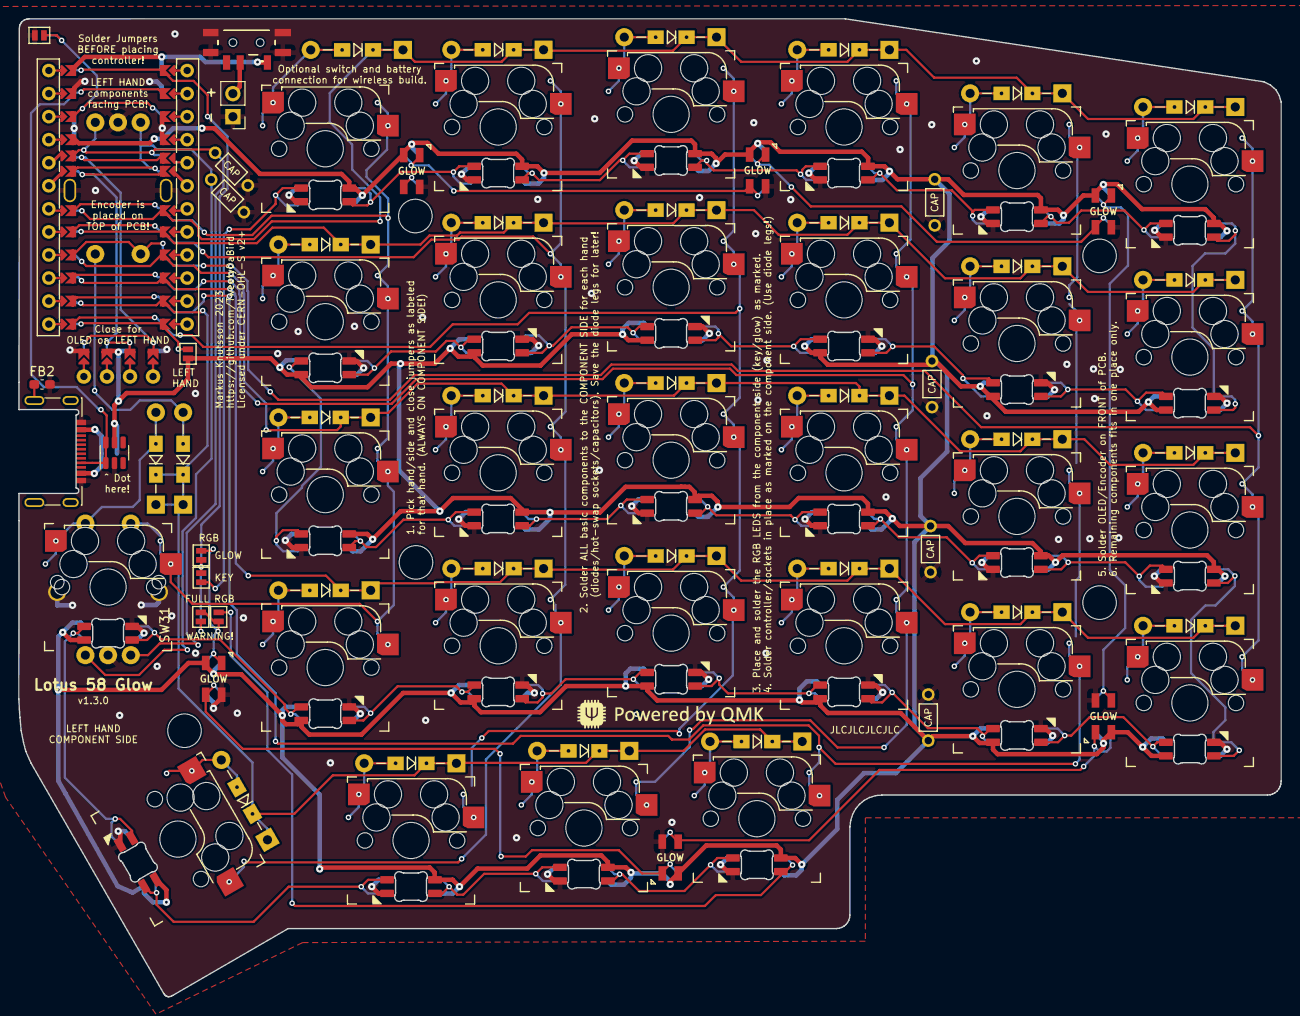
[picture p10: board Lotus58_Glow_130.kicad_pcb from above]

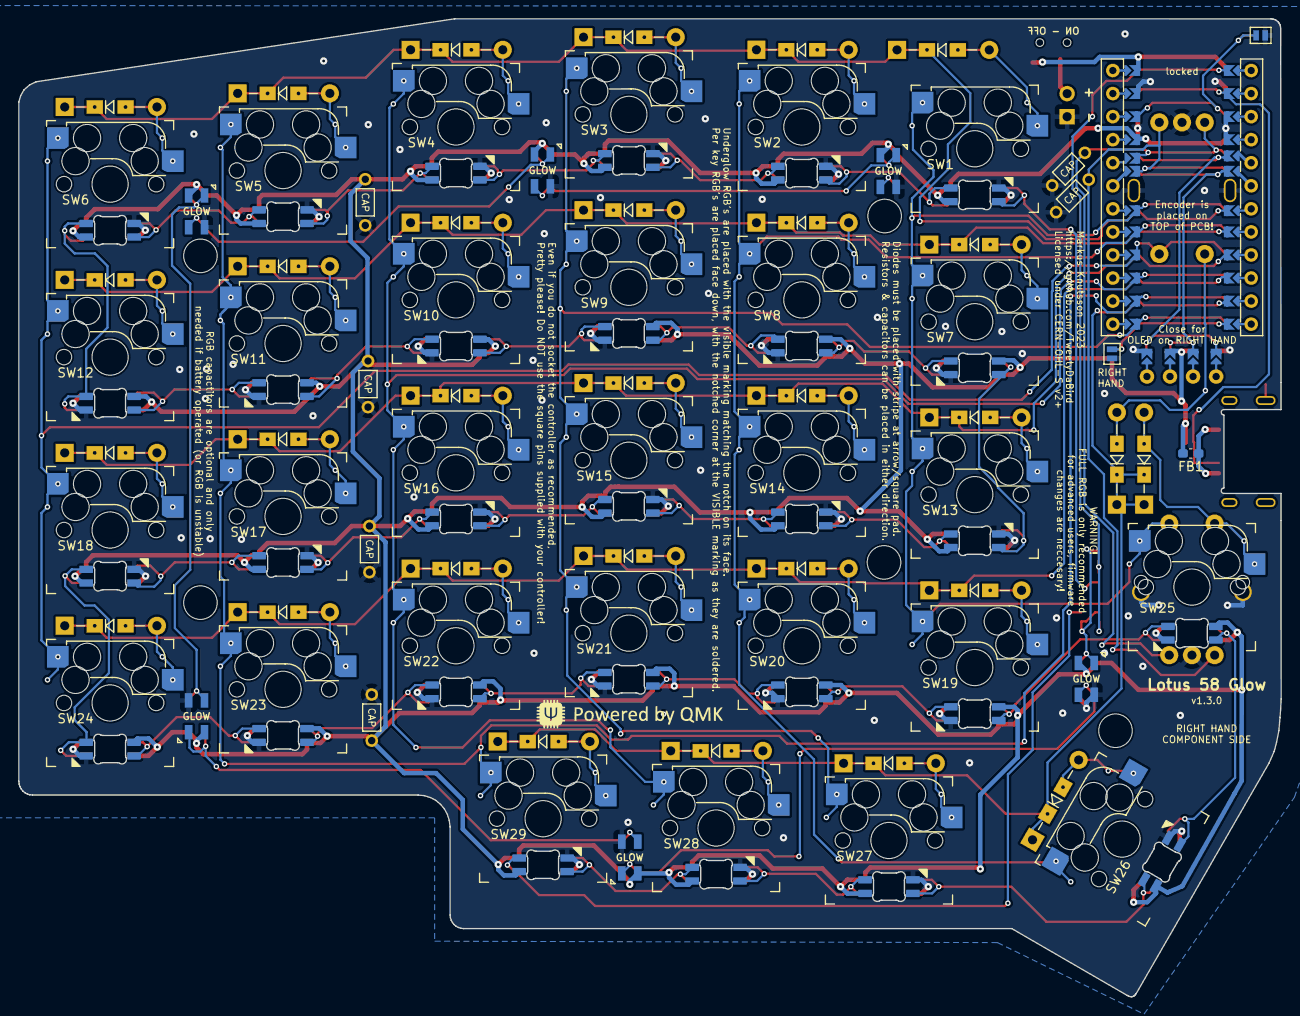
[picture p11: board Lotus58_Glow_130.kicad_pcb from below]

Board: 2 copper layers, 139.1 x 107.7 mm, 125 parts (36 on the bottom side), 91 nets.

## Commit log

2022-06-01 Prep for merge
    [Lotsu58_Glow.step, Lotus58_Glow.kicad_pcb, Lotus58_Glow.sch]
2022-06-02 v1.24 prototype
    [Lotus58_Glow.kicad_pcb, Lotus58_Glow.kicad_sch]
2022-06-10 Added viewable schematic
    [Lotus58_Glow.kicad_sch]
2022-09-14 v1.24
    Tweaks to silkscreen, reworked RGB jumpers.
    [Lotus58_Glow.kicad_pcb, Lotus58_Glow.kicad_sch]
2022-10-11 updated firmware
    [Lotus58_Glow.kicad_pcb]
2022-10-13 v1.24 updates
    Moved OLED 1 mm down
    Added footprint for SRV05-04 ESD protection on TRRS
    Silkscreen improvements
2022-10-24 Moving v1.24 to testing
    [Lotus58_Glow.kicad_pcb, Lotus58_Glow.kicad_sch]
2022-10-24 Trying USB C
    [Lotus58_Glow.kicad_pcb, Lotus58_Glow.kicad_sch]
2022-10-25 Lotus 58 C v1.0.0
    Moved to full SMD and USB-C
    [Lotsu58_Glow.step, Lotus58_C.kicad_pcb, Lotus58_C.kicad_sch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]
2022-10-25 Lotus C
    Minor tweaks
    SMD capacitors
    [Lotus58_C.kicad_pcb, Lotus58_C.kicad_sch]
2022-10-25 Glow v1.24
    Final tweaks
    [Lotus58_Glow.kicad_pcb, Lotus58_Glow.kicad_sch]
2022-10-25 Remove left over prototype files
2022-10-25 Renamed folders
    [Lotsu58_Glow.step, Lotus58_C.kicad_pcb, Lotus58_C.kicad_sch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]
2022-10-25 removed orig files
    [Lotsu58_Glow.step]
2022-11-02 Adding Lotus WL
    [Lotus58_WL.kicad_pcb, Lotus58_WL.kicad_sch]
2022-11-11 Minor tweaks
    [Lotus58_C.kicad_pcb, Lotus58_Glow.kicad_pcb, Lotus58_Glow.kicad_sch]
2022-11-23 v1.24 tweaks
    [Lotus58_Glow.kicad_sch]
2022-11-23 General cleanup and rename
    [Lotus58_C.kicad_pcb, Lotus58_Glow.kicad_pcb, Lotus58_Glow.kicad_sch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]
2022-11-29 silkscreen update v1.2.4
    [Lotus58_Glow_123.kicad_pcb, Lotus58_Glow_124.kicad_pcb]
2022-12-09 v1.2.4
    Ordered prototype
    [Lotus58_Glow_124.kicad_pcb, Lotus58_Glow_124.kicad_sch]
2023-02-18 Updated Firmware
    Corrected encoder index
2023-02-25 created wireless
    [Lotus58_Glow_124.kicad_pcb, Lotus58_Glow_124.kicad_sch]
2023-05-26 Revert "Delete Lotus 58 Glow/v1.25 directory"
    This reverts commit 31d979d12f78d2f2b7a7d2bcfd21e5f2126dafa7.
    [Lotus58_Glow.kicad_pcb, Lotus58_Glow.kicad_sch]
2023-05-26 v1.2.5
    Redesign of ProMicro socket
    [Lotus58_Glow_125.kicad_sch]
2023-05-26 Created rp2040 variant
    [Lotus58_RP-C.kicad_pcb, Lotus58_RP-C.kicad_sch]
2023-06-09 v1.3.0 initial
    New version with USB C and a centered controller footprint
    [Lotus58_Glow_130.kicad_pcb, Lotus58_Glow_130.kicad_sch]
2023-06-09 Revert "Merge branch 'development' into prototype"
    This reverts commit 35509e389ef8b26fb35347eea18a2192f52b11e9.
2023-07-26 Added 1.3.1
    minor corrections on jumper pads
    [Lotus58_Glow_131.kicad_pcb, Lotus58_Glow_131.kicad_sch]
2023-08-06 Regenerated DXF files
    Keep in mind, there is no tool kerf in these files, so that will need to be added as per your manufacturers choice
    [FR4_Bottom_Plate.kicad_pcb, FR4_Bottom_Plate.step, FR4_Bottom_Plate_TENT.kicad_pcb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]
2023-08-26 Version 1.32
    Tweaks, and RGB rework
    [Lotus58_Glow_132.kicad_pcb, Lotus58_Glow_132.kicad_sch]
2023-08-26 Renamed folder to Classic/USB-C
    [Lotus58_Glow_111.kicad_pcb, Lotus58_Glow_111.sch, Lotus58_Glow_123.kicad_pcb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]
2023-08-26 Housekeeping after merge
    [Lotus58_Glow_125.kicad_sch, Lotus58_Glow_130.kicad_pcb, Lotus58_Glow_130.kicad_sch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]
2023-08-26 v1.32
    Minor concessions for 3D printing
    [Lotus58_Glow_132.kicad_pcb, Lotus58_Glow_132.kicad_sch]
2023-08-26 v1.32 superseedes 1.31
    [Lotus58_Glow_132.kicad_pcb, Lotus58_Glow_132.kicad_sch]
2023-08-29 v1.33 superseedes 1.31
    Minor fixes to make 3D printing easier
    [Lotus58_Glow_132.kicad_pcb, Lotus58_Glow_132.kicad_sch, Lotus58_Glow_133.kicad_pcb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]
2023-08-30 v1.26 initial
    [Lotus58_Glow_126.kicad_pcb, Lotus58_Glow_126.kicad_sch]
2023-08-30 v1.26 final
    [FR4_Bottom_Plate.step, FR4_Bottom_Plate_TENT.step, FR4_Top_Plate_BLANK.step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]
2023-09-12 Updated plates
    Plates now have no copper layer, both preparing for wireless, and to avoid scratches/shorting, if OLED etc. is not soldered with flat pads.
    [FR4_Bottom_Plate.kicad_pcb, FR4_Bottom_Plate_TENT.kicad_pcb, FR4_Top_Plate_BLANK.kicad_pcb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]
2023-09-12 Updated Plates
    Prep for wireless, removing copper fill.
    [FR4_Bottom_Plate.kicad_pcb, FR4_Bottom_Plate_TENT.kicad_pcb, FR4_Top_Plate_BLANK.kicad_pcb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]
2023-09-12 v1.30 to released
    [Lotus58_Glow_130.kicad_pcb, Lotus58_Glow_130.kicad_sch]
2023-09-13 Corrected filename for v1.33 files
    [Lotus58_Glow_133.kicad_pcb, Lotus58_Glow_133.kicad_sch]
2023-09-13 v1.26 Release
    Stupid Git
    [Lotus58_Glow_126.kicad_pcb, Lotus58_Glow_126.kicad_sch]
2023-09-13 Revert "Merge pull request #53 from TweetyDaBird/release"
    This reverts commit d5395b9879702c31b6de7b44cd45c4487da02165, reversing
    changes made to 721366541e1b3daa08e8a27e832954bcb38f5212.
    # Conflicts:
    # .gitignore
    # Lotus 58 Classic/v1.26/Lotus58_Glow_126.kicad_pcb
    [FR4_Bottom_Plate.kicad_pcb, FR4_Bottom_Plate.step, FR4_Bottom_Plate_TENT.kicad_pcb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]
2023-09-13 Fixing my mistakes...
    [Lotus58_Glow_125.kicad_sch, Lotus58_Glow_126.kicad_pcb, Lotus58_Glow_126.kicad_sch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]
2023-10-14 Fixed silk screen inconsistencies
    [Lotus58_Glow_126.kicad_pcb, Lotus58_Glow_133.kicad_pcb, Lotus58_Glow_133.kicad_sch]
2023-10-14 testing wireless
    [Lotus58_WL.kicad_pcb, Lotus58_WL.kicad_sch, Lotus58_unWired_v1_00.kicad_pcb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]
2023-11-22 Lotus 58 USB-C v1.40
    Initial commit
    [Lotus58_Glow_140.kicad_pcb, Lotus58_Glow_140.kicad_sch]
2023-11-22 Lotus 58 Classic v1.27
    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
    [Lotus58_Glow_127.kicad_pcb, Lotus58_Glow_127.kicad_sch]
2023-11-22 Revert "Lotus 58 Classic v1.27"
    This reverts commit 127257085023c495304368bac738313ddacfc2f8.
    [Lotus58_Glow_127.kicad_pcb, Lotus58_Glow_127.kicad_sch]
2023-11-22 L58 C v1.40
    fix silkscreen
    [Lotus58_Glow_140.kicad_pcb]
2023-12-16 Created STEP files for 3D model
    [Lotus58_Glow_127.kicad_pcb, Lotus58_Glow_127.kicad_sch, Lotus58_Glow_140.kicad_pcb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]
2023-12-27 tweak v1.28
    [Lotus58_Glow_125.kicad_sch, Lotus58_Glow_128.kicad_pcb]
2023-12-27 Initial commit v1.28
    [Lotus58_Glow_128.kicad_sch]
2023-12-27 Removing unsuitable relaeases
    [Lotus58_Glow_131.kicad_pcb, Lotus58_Glow_131.kicad_sch, Lotus58_Glow_132.kicad_pcb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]

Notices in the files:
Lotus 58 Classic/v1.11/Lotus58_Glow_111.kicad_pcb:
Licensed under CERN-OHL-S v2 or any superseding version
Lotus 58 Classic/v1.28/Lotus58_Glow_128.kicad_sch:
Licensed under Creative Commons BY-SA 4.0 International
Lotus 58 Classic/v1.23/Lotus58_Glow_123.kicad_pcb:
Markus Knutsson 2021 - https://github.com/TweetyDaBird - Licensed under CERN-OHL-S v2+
